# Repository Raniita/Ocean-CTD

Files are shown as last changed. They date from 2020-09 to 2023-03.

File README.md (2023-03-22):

# Ocean-CTD


A CTD device’s primary function is to detect how the conductivity and temperature of the water column changes relative to depth.
This CTD obtain the values of colored dissolved organic matter (CDOM), Phycoerythrin (PE) and Chlorophyll (CHL).

## Requirements

* `GIT`
* `Python`
* _Optional_ Use Shell Script to execute the associated software (view folder `shell`).

### Based on:
Designed using a master-slave communication. An Arduino is doing the slave, and the mastering role is doing by other devices, like a phone or a laptop.

#### Probe (v3)

* Go to folder `v3` in order to view the specific documentation for that version!

#### Probe (v2)


* Arduino UNO
* USR ES1 W5500
* Custom PCB for cyclop cable conector
* I2C Logic converter, 3.3V to 5V
* PoE passive splitter, Ethernet + 5V
* [Cable (UTP) 26AWG (PoE over it)](https://bluerobotics.com/store/cables-connectors/cables/cab-nbpuf-4utp-26awg/)

##### Connections
Powering the Arduino with Ethernet PoE, and connecting it to a Router. The Router spawns a WiFi called "Boat", that allow the communication over laptop-CTD. On Router, we configure IP static for the CTD. 

##### Programs
Using a python based program to ask the CTD all values sensors, saving to a CSV and live plotting all the received values.

* View folder `CTD_controller`.

### Used sensors:
* [Turner Cyclops-7F CDOM](https://www.turnerdesigns.com/cyclops-7f-submersible-fluorometer)
* [Turner Cyclops-7F PE](https://www.turnerdesigns.com/cyclops-7f-submersible-fluorometer)
* [Turner Cyclops-7F CHL](https://www.turnerdesigns.com/cyclops-7f-submersible-fluorometer)
* [Depth/Pressure Sensor MS5837-30BA](https://bluerobotics.com/store/sensors-sonars-cameras/sensors/bar30-sensor-r1/)
* [Temperature TSYS01](https://bluerobotics.com/store/sensors-sonars-cameras/sensors/celsius-sensor-r1/)

### Disclaimer
This is a research version of CTD. Currently is on development.

This CTD is used by the research group [Mar Menor UPCT](https://ocean.upct.es/).

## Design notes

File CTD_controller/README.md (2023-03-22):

# CTD_controller
Python software related to probe mastering task.

## Summary of files

* `data_logger.py`. Main program of sampling profiles at sea.
* `data_logger_emergencia.py`. Emergency program to add depth manually.
* `data_logger_lab.py`. Sample measurement program in the laboratory.
* `interactive_test.py`. Simple program to contact the probe via commands.
* `simulate_ctd.py`. Probe simulator to develop new data capture programs.
* `gps_test1.py`. Usage example of USB GPS sensor.
* `salinity.py`. Python module to calculate salinity from electrical conductivity.
* `calculo_salinidad.ipynb`. Notebook to check the salinity calculation module.

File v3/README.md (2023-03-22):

# Upgrade to v3

## Features

* Add electrical conductivity ([ES-2](https://www.metergroup.com/en/meter-environment/products/es-2-electrical-conductivity-temperature-sensor)) sensor to hardware prototype. 
* Remove temperature sensor (TSYS01) because constraints of space.
* General cleaning of code. Try to reduce program size.
* New API endpoint on Hardware, keyword: ``ce``
* API endpoint ``ping``, returns info about hardware version.

## API Endpoints on Hardware:
* ``cdom``
* ``phy``
* ``chl``
* ``ms5``
* ``ce``
* ``ping``

## Tests

*Note: tests using tap water*

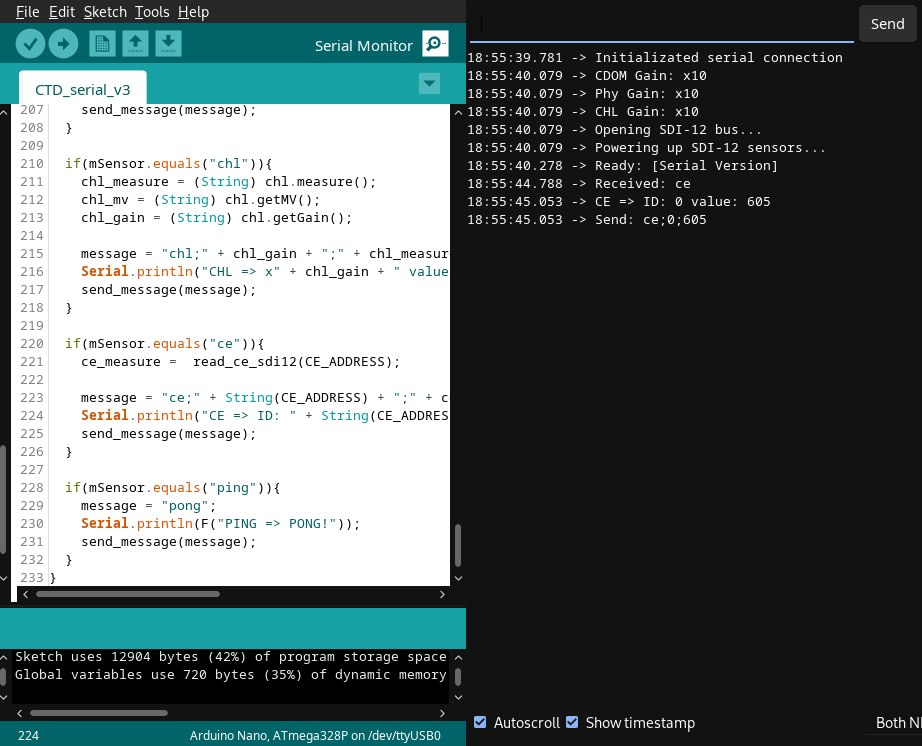
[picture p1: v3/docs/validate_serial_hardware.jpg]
Validate interactive_test


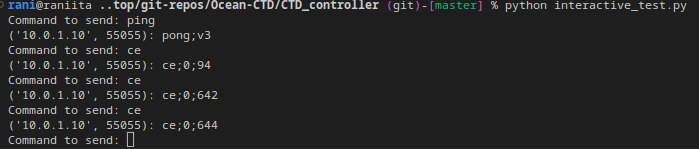
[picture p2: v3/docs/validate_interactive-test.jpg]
Validate serial_v3


## Physical connections

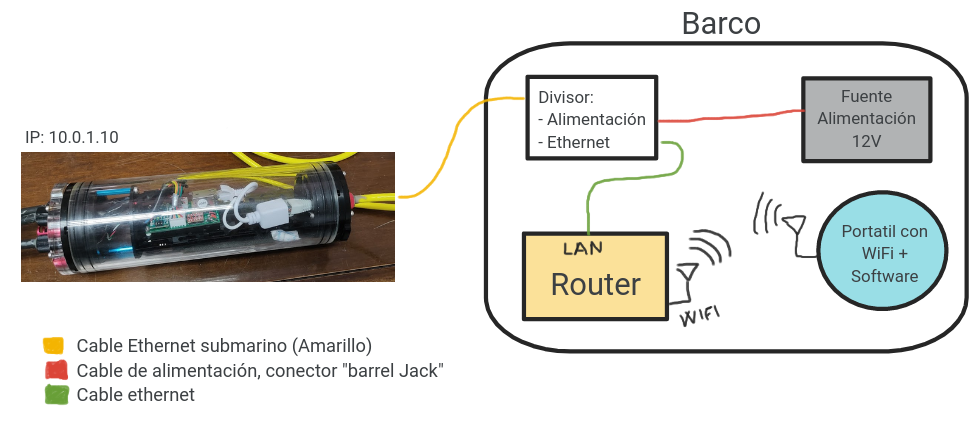
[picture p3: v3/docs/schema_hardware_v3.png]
Schema V3


## Connector for ES-2 Sensor

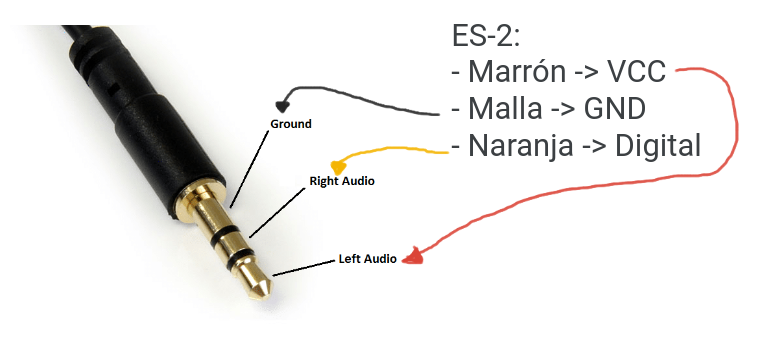
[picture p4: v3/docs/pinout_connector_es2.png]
Pinout ES-2 Connector


## Deploy notes

* Yellow Router USB cable could be connect to power brick (example: mobile phone charger). There isnt data flowing in that USB, only power.
* Yellow Router IP: 10.0.1.1, using OpenWRT. Password: _the classic ones_
* The Probe has Static IP (10.0.1.10), forced by the router.
* The Router expose the WiFi called `Boat`. Its able to use and should connect OK with the probe.

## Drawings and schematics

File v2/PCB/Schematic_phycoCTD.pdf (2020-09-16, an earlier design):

I/O Connections | GND

## Verde

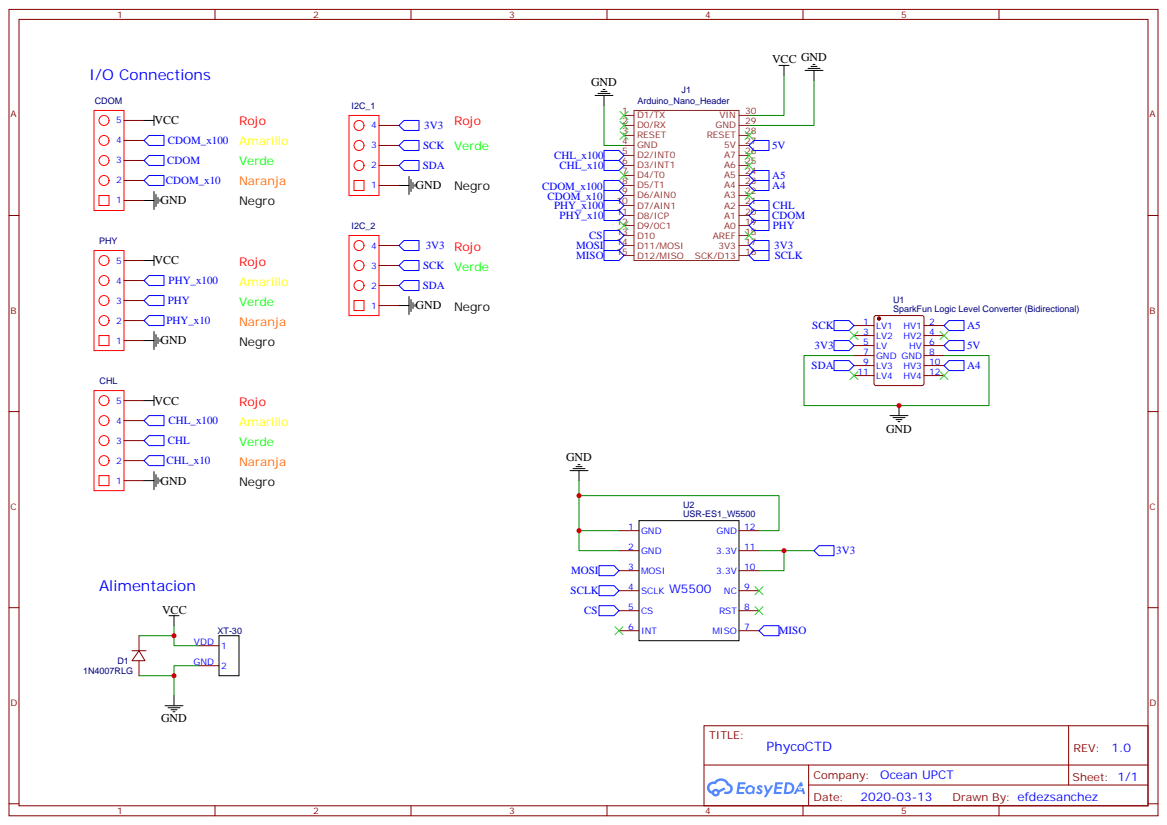
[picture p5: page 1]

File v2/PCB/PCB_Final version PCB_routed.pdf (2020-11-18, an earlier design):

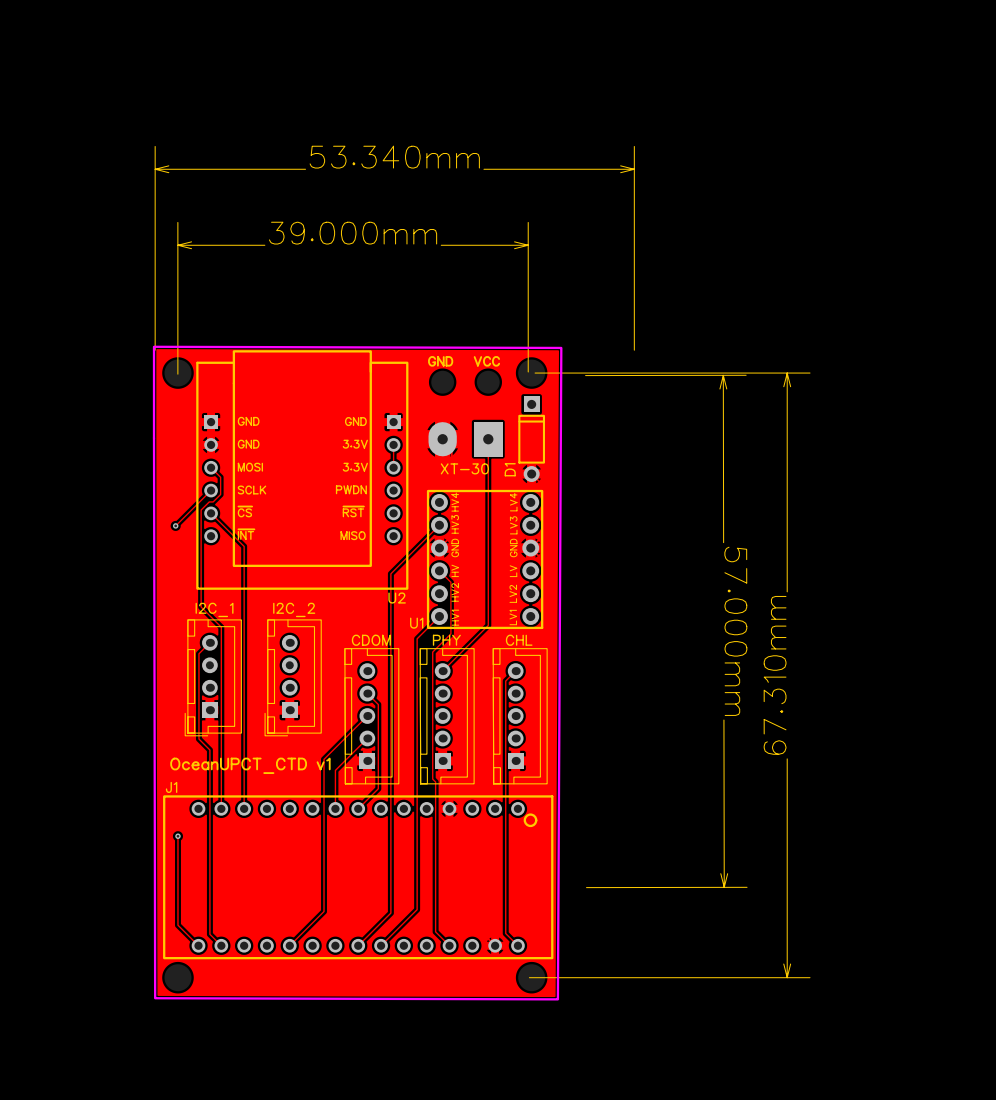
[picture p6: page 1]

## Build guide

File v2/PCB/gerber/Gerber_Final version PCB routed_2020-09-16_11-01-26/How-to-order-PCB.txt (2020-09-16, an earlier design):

How to Order PCB

Please refer to:
https://docs.easyeda.com/en/PCB/Order-PCB

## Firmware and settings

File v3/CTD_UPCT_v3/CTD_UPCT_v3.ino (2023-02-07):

//====================================================================
//============================= Librarys =============================
//====================================================================
#include <avr/pgmspace.h>
//#include <TSYS01.h>
#include <MS5837.h>
#include <cyclopSensor.h>
#include <Wire.h>
#include <SPI.h>
#include <SDI12.h>

#include <Ethernet.h>
#include <EthernetUdp.h>

//====================================================================
//============================= Configurations =======================
//====================================================================

// Serial configuration
#define BAUDRATE 115200

// Cyclops Sensors
// Plateado
#define cdom_type "cdom"
#define cdom_id '1'
#define cdom_read A1
#define cdom_x10 5
#define cdom_x100 6
#define cdom_maxPPB 1500

// Negro
#define phy_type "phy"
#define phy_id '2'
#define phy_read A0
#define phy_x10 7
#define phy_x100 8
#define phy_maxPPB 750

// Amarillo
#define chl_type "chl"
#define chl_id '3'
#define chl_read A2
#define chl_x10 2
#define chl_x100 3
#define chl_maxPPB 500

// SDI-12. Sensor Conductividad
#define SDI_DATA_PIN 9
#define SDI_POWER_PIN 4
#define CE_ADDRESS 0

// UDP configs
char packetBuffer[UDP_TX_PACKET_MAX_SIZE];
String datReq;  //String for our data
int packetSize; //Size of the packet

//====================================================================
//============================= Definitions ==========================
//====================================================================

// Sensores
cyclopSensor cdom(cdom_id, cdom_read, cdom_x10, cdom_x100);
cyclopSensor phy(phy_id, phy_read, phy_x10, phy_x100);
cyclopSensor chl(chl_id, chl_read, chl_x10, chl_x100);

MS5837 presion;
//TSYS01 temp;

bool presion_fail = false;

// Utilidades
EthernetUDP udp;

// SDI-12
SDI12 mySDI12(SDI_DATA_PIN);

//====================================================================
//=========================== Setup ==================================
//====================================================================

void setup(){
  // Local configs
  byte mac[6] = { 0x90, 0xA2, 0xDA, 0x2A, 0xB8, 0xCE };
  unsigned int local_port = 55055;

  // IP Static config (Router Amarillo == DHCP)
  IPAddress ip(10, 0, 1, 10);
  IPAddress gw(10, 0, 1, 1);
  IPAddress my_dns(1, 1, 1, 1);
  IPAddress subnet(255, 255, 255, 0);

  unsigned int server_port = 45045;

  ///////// START
  
  Serial.begin(BAUDRATE);
  Serial.println(F("Initializated serial connection"));
  delay(300);

  // Configuracion cyclops
  cdom.setMaxPPB(cdom_maxPPB);
  phy.setMaxPPB(phy_maxPPB);
  chl.setMaxPPB(chl_maxPPB);

  Serial.print(F("CDOM Gain: x"));
  Serial.println((String) cdom.getGain());
  Serial.print(F("Phy Gain: x"));
  Serial.println((String) phy.getGain());
  Serial.print(F("CHL Gain: x"));
  Serial.println((String) chl.getGain());

  // Configuracion Ethernet
  Serial.println(F("Initialize Ethernet with DHCP:"));

  // Static w5100
  //Ethernet.begin(mac, ip, my_dns, gw, subnet); 
  
  // DHCP
  if(Ethernet.begin(mac) == 0){
    // 1 min aprox to fail
    Serial.println(F("Error on Ethernet. DHCP Server not found."));
    Serial.println(F("Setting static IP Adress."));
    Ethernet.begin(mac, ip, my_dns, gw, subnet); 
    //while(true){
    //  delay(1);
    //}
  }

  delay(1000);

  udp.begin(local_port);
  Serial.print(F("IP: "));
  Serial.println(Ethernet.localIP());
  Serial.print(F("Port: "));
  Serial.println(local_port);

  // Configuracion I2C sensors
  Wire.begin();
  delay(100);

  int retry = 0;
  
  // Go UP Sensors
  //temp.init();
  while (!presion.init()){
    if(retry > 10) {
      presion_fail = true;
      break;
    } else {
      retry++;
    }

    Serial.println(F("Presion sensor failed"));
    delay(2000);
  }
  
  if(presion_fail == false){
    presion.setModel(MS5837::MS5837_30BA);
    presion.setFluidDensity(1029); // kg/m^3 (1029 for seawater)
  }

  // SDI-12
  Serial.println(F("Opening SDI-12 bus..."));
  mySDI12.begin();

  // Power UP SDI-12 Sensors
  if(SDI_POWER_PIN > 0){
    Serial.println(F("Powering up SDI-12 sensors..."));
    pinMode(SDI_POWER_PIN, OUTPUT);
    digitalWrite(SDI_POWER_PIN, HIGH);
  }

  Serial.println(F("Ready: "));
  delay(500);
}

//====================================================================
//============================= Loop =================================
//====================================================================

void loop(){
  packetSize = udp.parsePacket();

  if (packetSize > 0){
    udp.read(packetBuffer, UDP_TX_PACKET_MAX_SIZE); 
    datReq = packetBuffer;

    Serial.print(F("Received: "));
    Serial.println(datReq);
    memset(packetBuffer, 0, UDP_TX_PACKET_MAX_SIZE);
    
    // Mandamos lo recibido a la funcion
    // Si es alguno de nuestros sensores, mandamos la medida
    // Si no es, no hacemos nada
    read_sensor(datReq);
  }
}

//====================================================================
//====================== Functions as helpers! =======================
//====================================================================
String getValue(String data, char separator, int index){
    int found = 0;
    int strIndex[] = { 0, -1 };
    int maxIndex = data.length() - 1;

    for (int i = 0; i <= maxIndex && found <= index; i++) {
        if (data.charAt(i) == separator || i == maxIndex) {
            found++;
            strIndex[0] = strIndex[1] + 1;
            strIndex[1] = (i == maxIndex) ? i+1 : i;
        }
    }
    return found > index ? data.substring(strIndex[0], strIndex[1]) : "";
}

String read_ce_sdi12(int addr){
    String sdiResponse = "";           // clear the response string
    mySDI12.sendCommand(String(addr) + "M!");
    delay(30);                     // wait a while for a response
    while (mySDI12.available()) {  // build response string
        char c = mySDI12.read();
        if ((c != '\n') && (c != '\r')) {
          sdiResponse += c;
          delay(5);
        }
    }
   
    mySDI12.clearBuffer();
    delay(50);                 // delay between taking reading and requesting data
    
    // next command to request data from last measurement
    mySDI12.sendCommand(String(addr) + "D0!");
    delay(30);                     // wait a while for a response
    while (mySDI12.available()) {  // build string from response
        char c = mySDI12.read();
        if ((c != '\n') && (c != '\r')) {
            sdiResponse += c;
            delay(5);
        }
    }
    
    if (sdiResponse.length() > 1){
        mySDI12.clearBuffer();
        // Return CE, second value on sdiResponse
        return getValue(sdiResponse, '+', 1);
    } else {
        mySDI12.clearBuffer();
        return "-1";
    }
}

void send_message(String msg){
  udp.beginPacket(udp.remoteIP(), udp.remotePort());
  udp.print(msg);
  udp.endPacket();
  //memset(packetBuffer, 0, UDP_TX_PACKET_MAX_SIZE);
}

void read_sensor(String mSensor){
  // Formato de los mensajes:
  // <type>;<gain>;<measure>;<mv> (cyclops)
  // <type>;<pressure>;<temp>;<depth>;<altitude>
  // <type>;<measure> (i2c sensors)
  String message;
  
  if(mSensor == "cdom"){
    String cdom_measure = (String) cdom.measure();
    String cdom_mv = (String) cdom.getMV();
    String cdom_gain = (String) cdom.getGain();

    message = "cdom;" + cdom_gain + ";" + cdom_measure + ";" + cdom_mv;
    Serial.println("CDOM => x" + cdom_gain + " value: " + cdom_measure + " mV: " + cdom_mv);
    send_message(message);
  }

  if(mSensor == "phy"){
    String phy_measure = (String) phy.measure();
    String phy_mv = (String) phy.getMV();
    String phy_gain = (String) phy.getGain();

    message = "phy;" + phy_gain + ";" + phy_measure + ";" + phy_mv;
    Serial.println("PHY => x" + phy_gain + " value: " + phy_measure + " mV: " + phy_mv);
    send_message(message);
  }

  if(mSensor == "chl"){
    String chl_measure = (String) chl.measure();
    String chl_mv = (String) chl.getMV();
    String chl_gain = (String) chl.getGain();

    message = "chl;" + chl_gain + ";" + chl_measure + ";" + chl_mv;
    Serial.println("CHL => x" + chl_gain + " value: " + chl_measure + " mV: " + chl_mv);
    send_message(message);
  }

  if(mSensor == "ms5"){
    if(presion_fail == true){
      // Presion sensor doesnt boot. ERROR
      message = "ms5;error";
      Serial.println(F("MS5837 => Error, sensor doesnt boot"));

       send_message(message);
    } else {
      presion.read();
      String ms_pressure = (String) presion.pressure();
      String ms_temp = (String) presion.temperature();
      String ms_depth = (String) presion.depth();
      String ms_alt = (String) presion.altitude();

      message = "ms5;" + ms_pressure + ";" + ms_temp + ";" + ms_depth + ";" + ms_alt;
      Serial.println("MS5837 => " + ms_pressure + " mbar, " + ms_temp + " C, " +
                 ms_depth + " m, " + ms_alt + " m above sea");
      send_message(message);
    } 
  }

  //if(mSensor == "temp"){
  //  temp.read();
  //  ts_temp = (String) temp.temperature();

  //  message = "temp;" + ts_temp;
  //  Serial.println("TSYS01 => " + ts_temp + " C");
  //  send_message(message);
  //}

  if(mSensor.equals("ce")){
    String ce_measure =  read_ce_sdi12(CE_ADDRESS);

    message = "ce;" + String(CE_ADDRESS) + ";" + ce_measure;
    Serial.println("CE => ID: " + String(CE_ADDRESS) + " value: " + ce_measure);
    send_message(message);
  }

  if(mSensor == "ping"){
    message = "pong;v3";
    Serial.println(F("PING => PONG!"));
    send_message(message);
  }
}

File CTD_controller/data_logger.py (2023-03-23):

#!/usr/bin/env python
import pandas as pd
import matplotlib.pyplot as plt
from matplotlib.animation import FuncAnimation
from multiprocessing import Process
from datetime import datetime
import os, socket, time, csv
import gpsd

import salinity

# Plot
def live_plot(filename, station):
    """ Threaded func to get the CSV data and plotting it """
    
    # Ventana de datos
    win = 100     

    def animate(i):
        """ Animate Function """
        try:
            # Read the csv
            data = pd.read_csv(filename, delimiter=',')
            y_values = data['depth']
            x1_values = data['cdom [ppb]']
            last_cdom = str(x1_values.iloc[-1])
            x2_values = data['pe [ppb]']
            last_phy = str(x2_values.iloc[-1])
            x3_values = data['chl [ppb]']
            last_chl = str(x3_values.iloc[-1])
            x4_values = data['ce [uS/cm]']
            last_ce = str(x4_values.iloc[-1])
            x5_values = data['s [pps]']
            last_s = str(x5_values.iloc[-1])

            # Fix first row csv, empty values
            if(last_cdom == "cdom [ppb]"):
                last_cdom = "none"
                last_phy = "none"
                last_chl = "none"
                last_ce = "none"
                last_s = "none"

            # Limit the data
            imin = min(max(0, i - win), y_values.size - win)
            
            # Plotting all the data of the csv, show the last on legend
            plt.cla()
            plt.plot(x1_values[imin:i], y_values[imin:i], color="orange", label="cdom [ppb]")
            plt.plot([],[], ' ', label="CDOM: "+last_cdom)
            plt.plot(x2_values[imin:i], y_values[imin:i], color="blue", label="pe [ppb]")
            plt.plot([],[], ' ', label="PE: "+last_phy)
            plt.plot(x3_values[imin:i], y_values[imin:i], color="green", label="chl [ppb]")
            plt.plot([],[], ' ', label="CHL: "+last_chl)
            plt.scatter(0,0, color="red", label="ce [uS/cm]")
            plt.plot([],[], ' ', label="CE: "+last_ce)
            plt.scatter(0,0, color="yellow", label="s [pps]")
            plt.plot([],[], ' ', label="S: "+last_s)
            plt.legend(bbox_to_anchor=(1.05, 1), loc='upper left', borderaxespad=0.)
        except pd.errors.EmptyDataError:
            print (filename, " is empty")
        except IndexError:
            pass
        
        plt.xlabel('PPB')
        plt.ylabel('Depth (m)')
        plt.title("".join(("CDOM-PE-CHL on ", station)))
        plt.gcf().autofmt_xdate()
        plt.gca().invert_yaxis()
        plt.tight_layout()
        
    ani = FuncAnimation(plt.gcf(), animate, 3000)
    #ani.save(videofilename, writer='ffmpeg')

    plt.tight_layout()
    plt.show()
    
if __name__ == '__main__':
    # Arduino IP + port [10.0.1.10 DHCP del barco]
    arduino = ('10.0.1.10', 55055)
    buffersize = 1024

    # UPD Socket
    sock = socket.socket(socket.AF_INET, socket.SOCK_DGRAM)
    sock.bind(("", 45045))
    sock.settimeout(5)

    # Verify hardware version
    msg2send = "ping"
    sock.sendto(msg2send.encode(), arduino)
    try:
        recv_d, addr = sock.recvfrom(buffersize)
        data = recv_d.decode().split(";")
        pong = data[0]
        version = data[1]
        print(f"Hardware version: {version}")
    except:
        print("Unable to connect with probe")
        raise Exception

    station = input("Please introduce name of current station: ")
    start_timestamp = datetime.today().strftime("%d-%m-%Y")

    ## TODO:
    # Create day folder 
    #if not os.path.exists(start_timestamp):
    #    os.makedirs(start_timestamp)

    filename = "".join((station, "-", start_timestamp,".csv"))
    #videofilename = "".join((station, "-", start_timestamp,".mp4"))

    # Ask to use GPSd info?
    use_gpsd = input("Use GPS? [y/N]: ")
    if use_gpsd == "y":
        # GPSd en el router amarillo
        print("Using GPS on 10.0.1.1")
        gpsd.connect(host="10.0.1.1", port=2947)

        with open(filename, 'a', newline='') as f:
            if version == "v3":
                row = ["station","latitude", "longitude", "time", "depth", "temp1", "cdom [gain]", "cdom [ppb]", "cdom [mv]", "pe [gain]", "pe [ppb]", "pe [mv]", "chl [gain]", "chl [ppb]", "chl [mv]", "ce [uS/cm]", "s [pps]"]
            else:
                row = ["station","latitude", "longitude", "time", "depth", "temp1", "temp2", "cdom [gain]", "cdom [ppb]", "cdom [mv]", "pe [gain]", "pe [ppb]", "pe [mv]", "chl [gain]", "chl [ppb]", "chl [mv]"]
            writer = csv.writer(f, delimiter=',')
            writer.writerow(row)

        position = gpsd.get_current().position()
    else:
        with open(filename, 'a', newline='') as f:
            if version == "v3":
                row = ["station", "time", "depth", "temp1", "cdom [gain]", "cdom [ppb]", "cdom [mv]", "pe [gain]", "pe [ppb]", "pe [mv]", "chl [gain]", "chl [ppb]", "chl [mv]", "ce [uS/cm]", "s [pps]"]
            else:
                row = ["station", "time", "depth", "temp1", "temp2", "cdom [gain]", "cdom [ppb]", "cdom [mv]", "pe [gain]", "pe [ppb]", "pe [mv]", "chl [gain]", "chl [ppb]", "chl [mv]"]
            writer = csv.writer(f, delimiter=',')
            writer.writerow(row)

    
    print("Receiving data: ... \n")

    # Definition plot thread
    p = Process(target=live_plot, args=(filename, station,))
    p.start()

    while True:
        # cdom -> Respuesta: <type>;<gain>;<measure>;<mv> (cyclops)
        # phy -> Respuesta: <type>;<gain>;<measure>;<mv> (cyclops)
        # chl -> Respuesta: <type>;<gain>;<measure>;<mv> (cyclops)
        # ms5 -> Respuesta: <type>;<pressure>;<temp>;<depth>;<altitude>
        # temp -> Respuesta: <type>;<measure> (i2c sensors)
        # (v3) ce -> Respuesta: <type>;<addr>;<value> (sdi-12 sensor)

        msg2send = "ms5"
        sock.sendto(msg2send.encode(), arduino)
        try:
            recv_d, addr = sock.recvfrom(buffersize)
            data = recv_d.decode().split(";")
            if(data[1] == "error"):
                pressure = data[1]
                temp1 = data[1]
                depth = data[1]
                altitude = data[1]
            else:
                pressure = data[1]
                temp1 = data[2]
                depth = data[3]
                altitude = data[4]

                print(f"[MS5] Depth:{depth} Pressure:{pressure} Altitude:{altitude} Temp:{temp1}")

                # Save OK
                ms5_read = True
        except:
            ms5_read = False
            print("Error. No response for depth.")
            pass

        msg2send = "cdom"
        sock.sendto(msg2send.encode(), arduino)
        try:
            recv_d, addr = sock.recvfrom(buffersize)
            data = recv_d.decode().split(";")
            cdom_gain = data[1]
            cdom_ppb = data[2]
            cdom_mv = data[3]

            print(f"[CDOM] Gain:x{cdom_gain} PPB:{cdom_ppb} mV:{cdom_mv}")
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

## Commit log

2019-07-22 new version of sensor library
2019-07-24 tests in lab, something goes wrong
    [PruebaLab.ino, lab_test.ino]
2019-11-07 new version of arduino sketch
2019-11-13 Fix python 3.8 and add error messages
    [data_logger.py]
2019-11-22 CSV already working
    [2019-11-21-18:56:07e1.csv, 2019-11-21-19:03:03e1.csv]
2019-11-23 last fixes on scripts
    [2019-11-22-12:29:22e1.csv, 2019-11-22-12:39:51e1.csv]
2019-11-25 ethernet boot before i2c
2019-11-27 Cyclops library fixed, already ppbs working
    [interactive_test.py]
2019-11-29 live plot working. CTD fixed
    [2019-11-21-18:56:07e1.csv, 2019-11-21-19:03:03e1.csv, 2019-11-22-12:29:22e1.csv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]
2019-12-12 Delay fixed. Cyclops flagged some useless function
    [data_logger_lab.py]
2020-02-13 Small fixes on dataloggers
    [data_logger.py, data_logger_lab.py]
2020-09-16 Add PCB files
    [Gerber_BoardOutline.GKO, Gerber_BottomLayer.GBL, Gerber_BottomSolderMaskLayer.GBS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]
2023-02-07 feat: add ES-2 sensor to hardware v3
2023-02-07 feat: add img es-2 connector
2023-03-23 feat: add salinity to datalogger_lab & bug fixes
    [data_logger.py, data_logger_lab.py]
